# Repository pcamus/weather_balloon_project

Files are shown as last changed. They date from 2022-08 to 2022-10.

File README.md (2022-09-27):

# Weather balloon project

In this project I use a Raspberry Pi Pico and 2 extension modules to design a weather balloon experiment.

The purpose of this experiment is to measure flight parameters of the balloon (X,Y,Z acceleration, pressure and temperature).

The programming language is MicroPython.

## Hardware setup.

- A Raspbery Pi Pico.
- A [10-DOF IMU](https://www.waveshare.com/wiki/Pico-10DOF-IMU) from Waveshare.
- A battery module [Pico UPS A](https://www.waveshare.com/wiki/Pico-UPS-A) from Waveshare.

For the prototype I also use a [Quad GPIO Expander](https://www.waveshare.com/pico-quad-expander.htm) from Waveshare

*Prototype setup:*

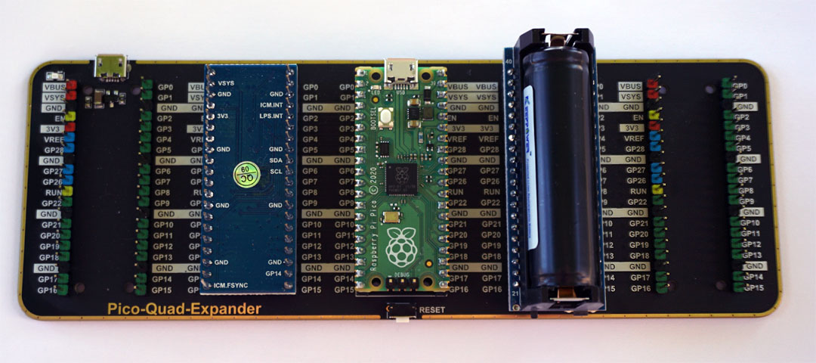
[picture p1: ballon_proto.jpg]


*The stacked version (wheight = 50 g) looks like that:*

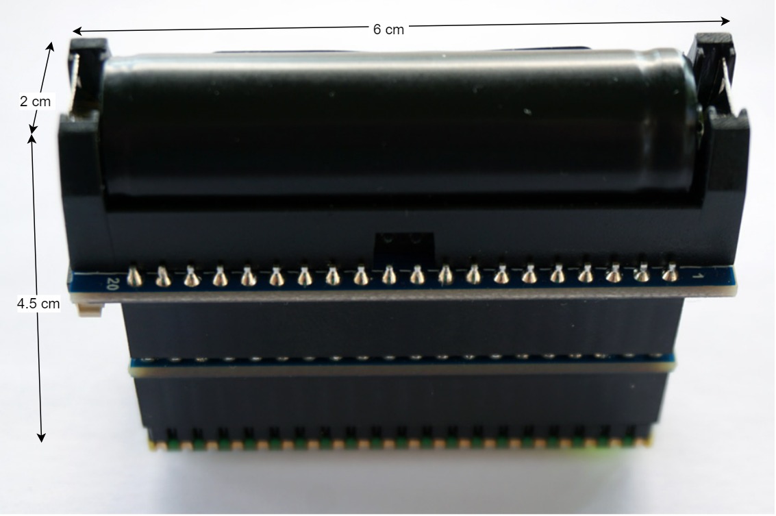
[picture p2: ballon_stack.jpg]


## Software (in MicroPython).

[acc_pt_log.py](acc_pt_log.py), performs data acquisition on the 10-DOF IMU. The code uses 2 modules icm20948_mod.py and
lps22 hb_mod.py (see embedded-sensors repository : [Pico_IMU_10DOF](https://github.com/pcamus/embedded-sensors/tree/main/Pico_IMU_10DOF/my_IMU_code))

The code appends X,Y,Z acceleration data from the ICM20948 chip to the binary file `acc.bin` and pressure + temperature from the LPS22HB chip to `Press_Temp.bin`.

Acceleration is sampled each 100 ms and pressure + temperature each second. Each value is converted into 2 bytes. 

[bin_to_csv.py](bin_to_csv.py), creates csv files from the binary files. 

## Enclosure.

A 3D enclosure with a removable lid was design with the Inventor software from Autodesk.

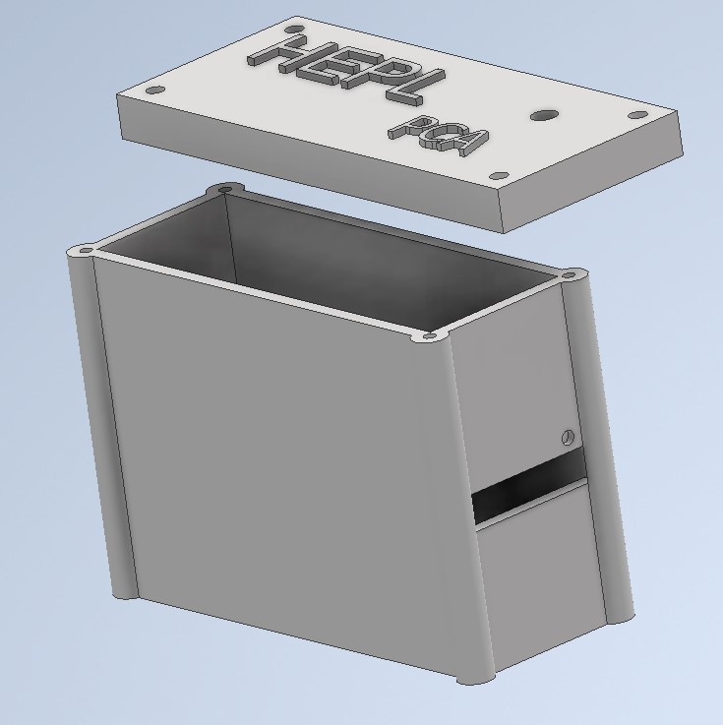
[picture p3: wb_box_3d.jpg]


Step and stl files are available in this repository.

Here is the view of the assembled system :

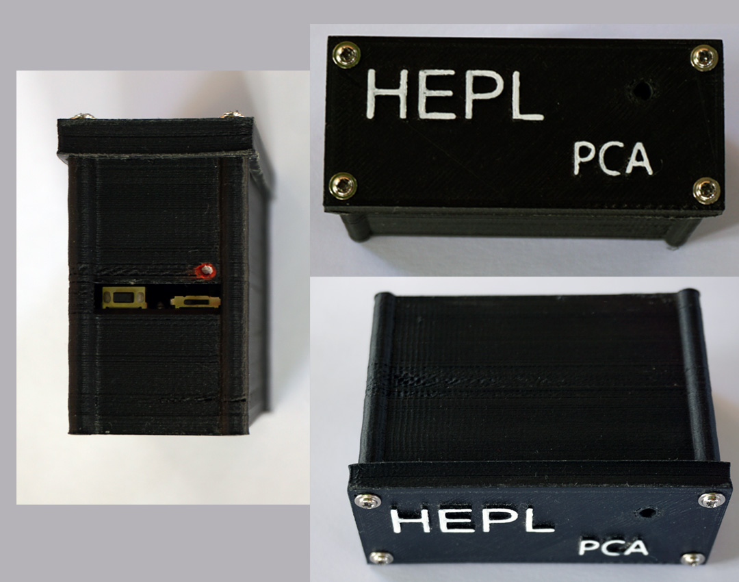
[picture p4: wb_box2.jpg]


The box was printed on an Anycubic i3 Mega with PLA filament.

The board assembly is simply slid into the box and wedged with a piece of foam on top.The start switch is located on the right of the side slot, the ON position is under the red and white dot.

Overall dimensions are 71 x 31 x 49 mm, weight is 84g.

## Using the system.

A manual with the procedure for using the system can be found [here](manual.md).

## Flight and results.

The module was launched by IRM on September 24, 2022.

See [here](flight_results) for the details.

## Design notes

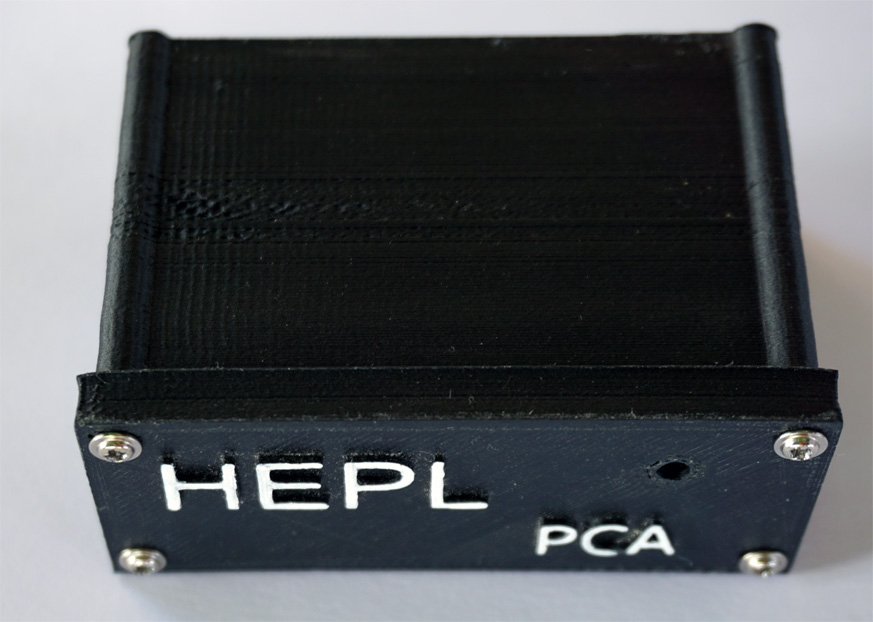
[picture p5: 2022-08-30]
wb_box1.jpg

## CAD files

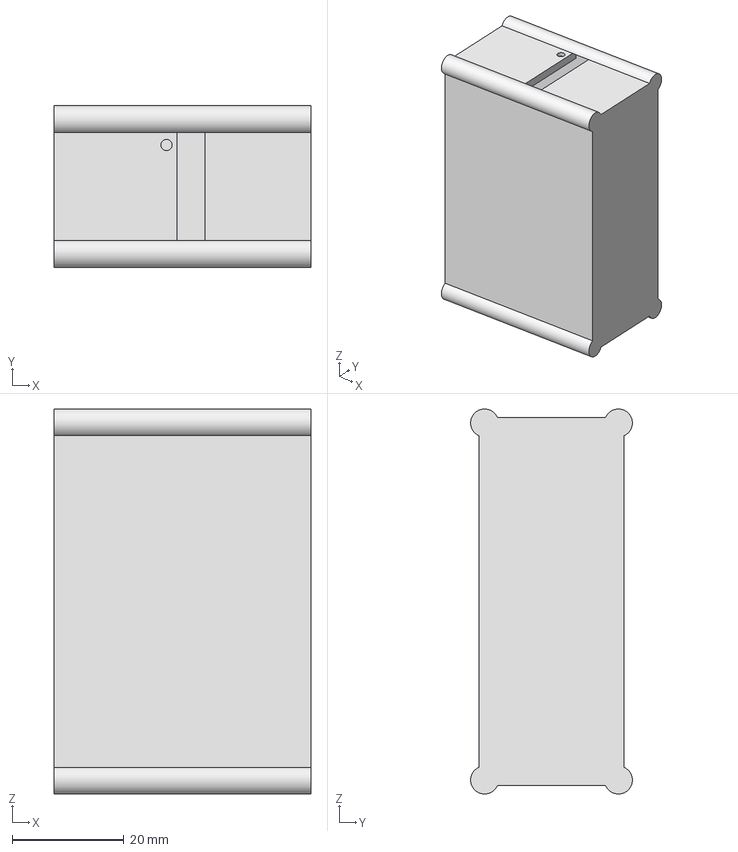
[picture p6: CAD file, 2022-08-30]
wb_box2.stp
46.0 x 29.0 x 69.0 mm

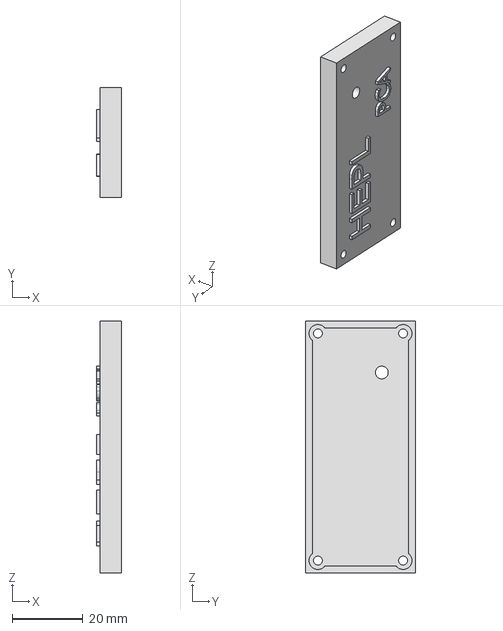
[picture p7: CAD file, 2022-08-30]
wb_box2_lid1.stp
7.00 x 31.0 x 71.0 mm

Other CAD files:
wb_box2.stl
wb_box2_lid1.stl

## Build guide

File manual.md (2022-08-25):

## How to use the system.

To program and retrieve files from the Raspberry Pi Pico I used the Thonny IDE.

I worked with two interpreters : 

- The default Thonny interpreter, running on my computer.
- The MicroPython interpreter running on the Pico board.

The interface is the following :

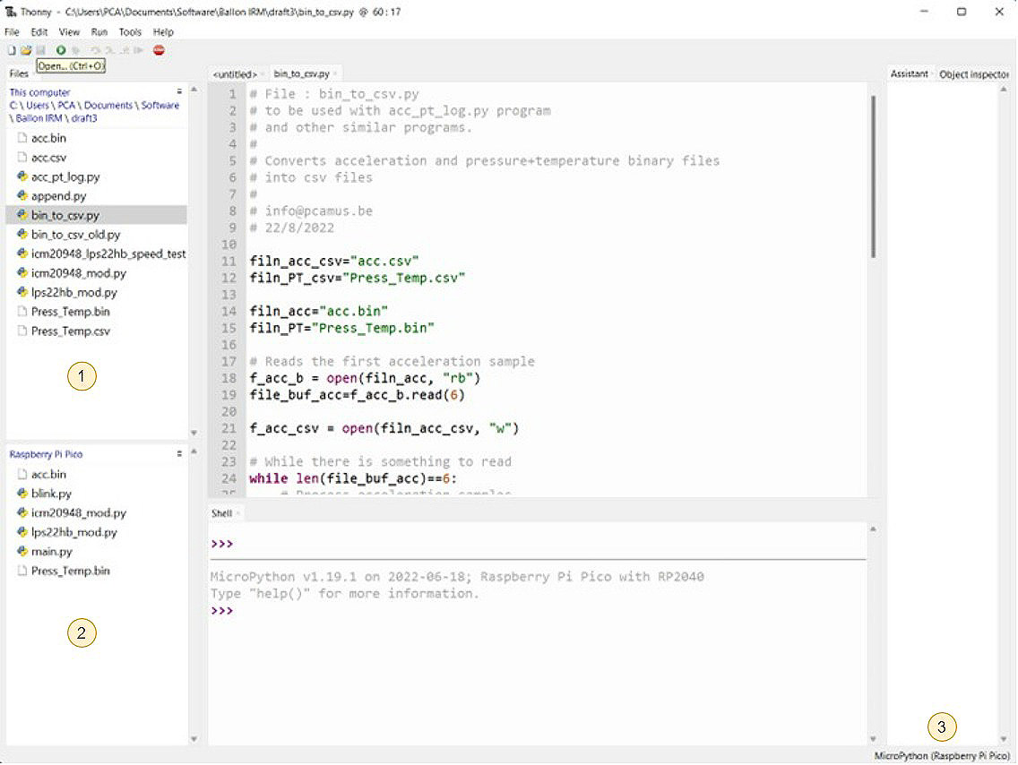
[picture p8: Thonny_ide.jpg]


- `1` is the current directory on my computer.
- `2` is the current directory on the Pico.
- `3` shows which interpreter is in use (to change click on this item).

To show the file windows click on View menu and then Files

*Interpreter choice :*

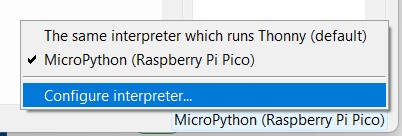
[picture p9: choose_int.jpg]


For information about installing MicroPython interpreter see [here](https://www.raspberrypi.com/documentation/microcontrollers/micropython.html).

### Program installation.

Connect the Pico to your computer with PICO-UPS-A board switch in OFF position.

In your working directory install `acc_pt_log.py`, `icm20948_mod.py`, `lps22hb_mod.py` and `bin_to_csv.py`

`icm20948_mod.py`, `lps22hb_mod.py` are in the embedded-sensors repository : [Pico_IMU_10DOF](https://github.com/pcamus/embedded-sensors/tree/main/Pico_IMU_10DOF/my_IMU_code)

Rename `acc_pt_log.py` as `main.py` (MicroPython starts automatically main.py at reset).

With the MicroPython interpreter selected, copy `main.py`, `icm20948_mod.py` and `lps22hb_mod.py` to the Pico (right click on the files then Upload to /)

Disconnect your computer. The logging will start when you switch ON the PICO-UPS-A and will last for a time equal to the value of the `LOG_TIME` variable (in `main.py`). The Pico LED will flash slowly twice indication that the initialisation of the chips is successful, then the LED will toggle at each sampling of the acceleration.

### Retrieving data files.

Connect the Pico to your computer with PICO-UPS-A board switch in OFF position and select the MicroPython interpreter.

This will automatically start a new acquisition, so stop it by clicking on the stop button. Then refresh the Raspberry Pi Pico file window (menu at the top right of the window).

Then click right successively on the `acc.bin` and `Press_Temp.bin` files and choose Download to... The files will be copied in your computer directory.

**Then switch to the default interpreter** (running on your computer) and run the `bin_to_csv.py` program. If you don't switch to the default interpreter the `bin_to_csv.py` program will try to create the csv files into the Pico flash memory which is not big enough for this !

After refreshing the file window, `acc.csv` and `Press_Temp.csv` will be there.

### Starting a new log session.

Connect the Pico to your computer with PICO-UPS-A board switch in OFF position and select the MicroPython interpreter.

This will automatically start a new acquisition, so stop it by clicking on the stop button. Then refresh the Raspberry Pi Pico file window (menu at the top right of the window).

Then click right successively on the `acc.bin` and `Press_Temp.bin` files and choose Delete. The files will be removed from the Pico flash memor thus leaving room for a new data logging.

Disconnect your computer. The logging will start when you switch ON the PICO-UPS-A.

### Using the data.

After conversion, two files are available : 

- `acc.csv` with the X,Y,Z acceleration values. In this setup the accelerations range from -32768 à +32767 corresponding to -2g to +2g and the sampling rate is 100 ms.
- `Press_Temp.csv` with pressure and temperature values. The pressure is in hPa and the temperature in Celsius degree with one decimal. The sampling rate is 10s.

A row with all 0 indicates the beginning of a new logging session.

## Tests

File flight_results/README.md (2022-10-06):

# Flight results

Due to an incorrect value for the flight duration in the MicroPython program, the data logging was only made for 30 minutes of which only 10 correspond to the flight (up to an altitude of 2600 m).

The flight peaked at 34 km altitude. Its total duration was 2h15.

**Pressure variation during the flight:**

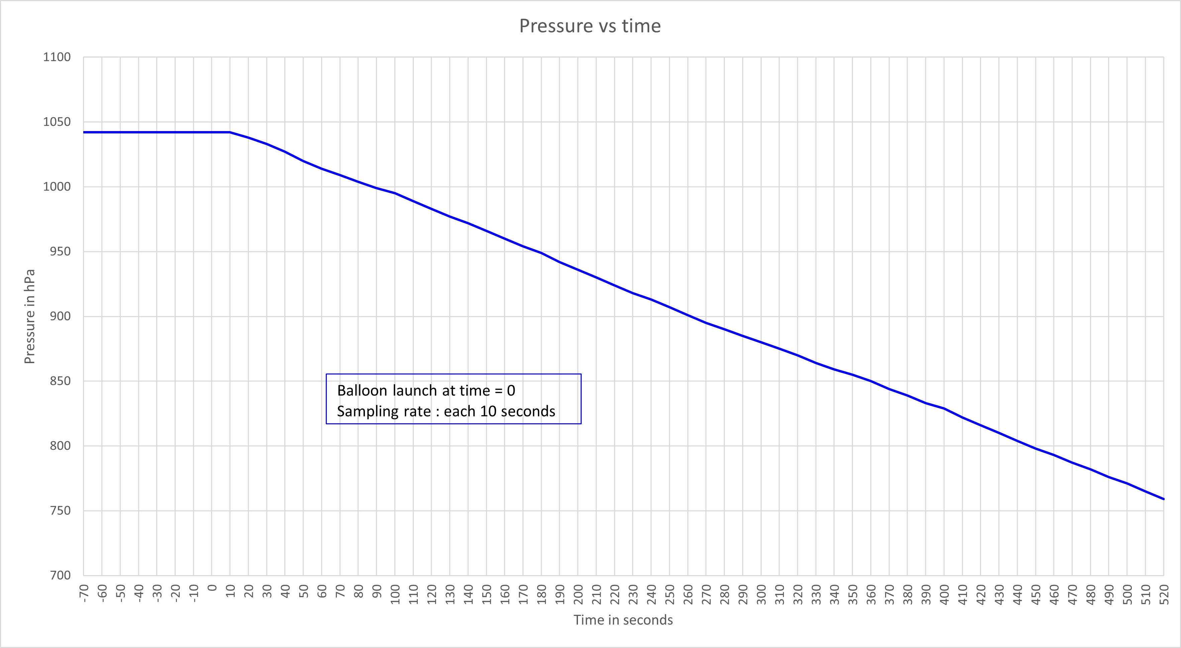
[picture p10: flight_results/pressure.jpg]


The formula giving altitude (h) versus pressure (p) is:  the following $h=\frac{R.T}{\mu.g}ln(\frac{p}{p_0})$

With : 

- h : altitude above ground
- R : ideal gaz constant = 8.3143 J/K.mol
- T : temperature at altitude h (in °K)
- $\mu$ : air molar mass = 0.02896 kg/mol
- g : gravity of earth = 9.81 m/$s^2$
- $p_0$ : pressure at ground

Substituing with the numerical values leads to $h=-29.2656\ T\ ln(\frac{p}{p_0})$

For example at t = 520 s, the measured pressure was 759 hPa , with a ground pressure $p_0$ of 1042 hPa and a temperature of 290.5°K, the altitude above ground h given by the formula is: **2694 m**.

*The altitude above ground given by the tracking at this moment was: **2960 m**.*

**Altitude calculated from the pressure vs altitude with constant rate of ascent:**

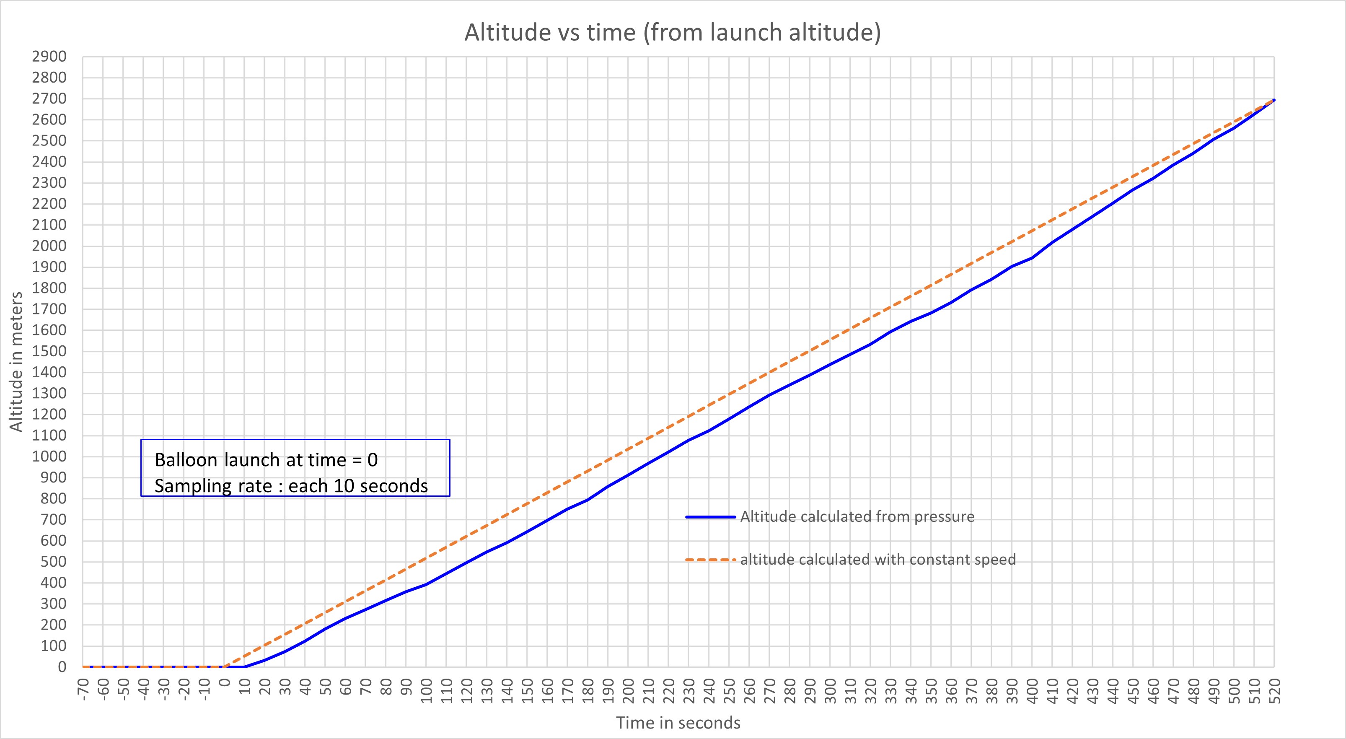
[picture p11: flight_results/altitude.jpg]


The average speed is **5.18 m/s**. 

Balloon speed calculation from Newton's law with its differential equation resolution is [here](balloon_equation.pdf). Integration is made with sympy : [edif_bal.py](edif_bal.py)

The difference between measured speed and calculated speed is due to our approximate knowledge of some balloon parameters.

\
**Vertical acceleration:**

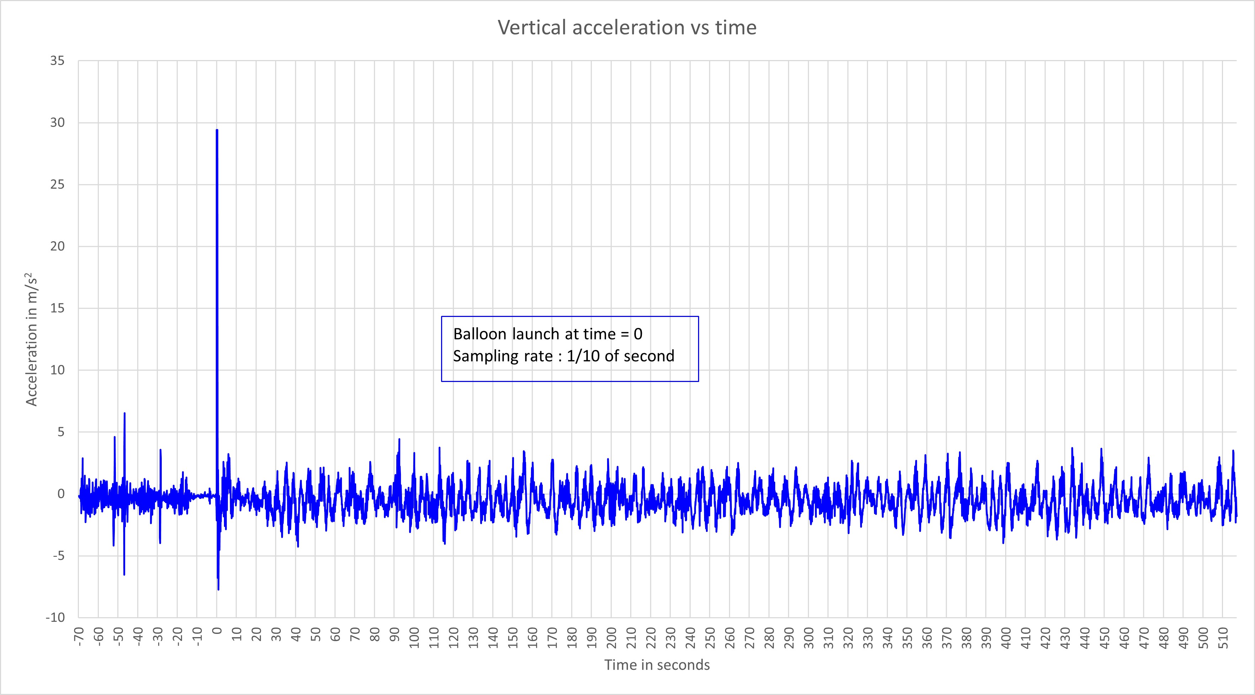
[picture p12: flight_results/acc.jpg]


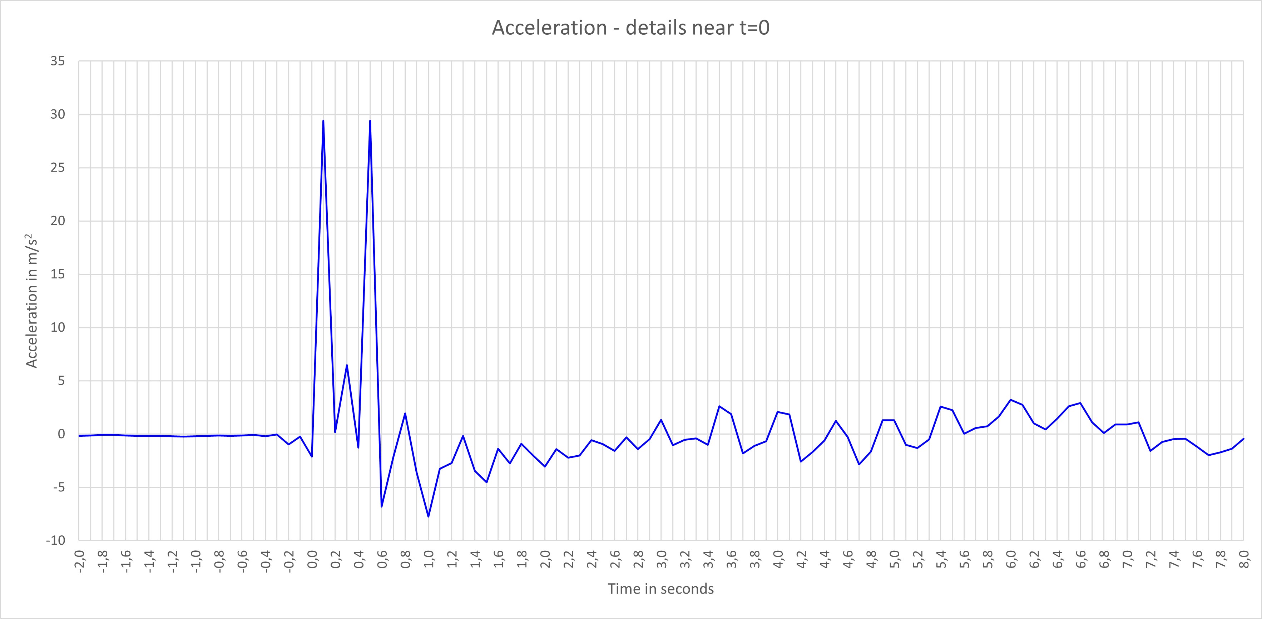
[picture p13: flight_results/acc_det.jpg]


The acceleration curve is not usable to compute the speed and altitude for several reasons:

- The time resolution (1/10e s) is too large to have a correct picture of the motion.
- There are too many vertical oscillations (mass-spring effect due to the balloon).
- The wind disturbs the motion...

\
Thank you to the IRM for allowing us to use its balloon and a very big thanks for the radio amateurs of the [UBA](https://www.uba.be/fr/radioamateurisme) who recovered the probe.

The flight dashboard is [here](https://grafana.v2.sondehub.org/d/HJgOZLq7k/basic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).

[Here is a pic of me ready to launch the balloon](IRM2209_03.jpg).

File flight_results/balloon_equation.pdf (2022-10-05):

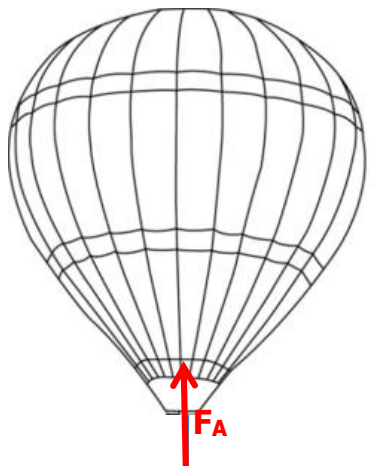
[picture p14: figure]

Weather balloon equation | philippe.camus@hepl.be | 1/4.

Weather balloon speed.

Equation.

List of forces:

FA Archimedes thrust.
P : balloon and payload weight. Ff : friction force in the air.

FA = ρair Vballoon g

P = mtotal g

Ff = ½ Cx ρair S v² = drag force.

Cx is the air penetration (or drag) coefficient
S the effective area of the object (largest section perpendicular to the movement). v is the vertical speed of the balloon

Newton’s equation: sum of the forces (with respective sign) = m a.

FA − P − FA = m total a = m total

dv(t)
dt

ρair Vballoon g − mtotal g −

1
2

CxρairS v

2
(t) = m total

dv(t)
dt

That could be written :

dv(t)
dt + Av

2
(t) − B = 0

With :

A =

1

2mtotal

CxρairS B = g (

ρair Vballoon

mtotal

− 1)

P

Ff

Limit values.

Maximum boardable weight at take-off (acceleration must be positive):

ρair Vballoon g

mtotal

− g = B =

dv(t)
dt ≥ 0 → mtotal ≤ ρair Vballoon

B>0 is needed to allow the take-off of the balloon.

Limit speed: speed for which the acceleration is zero.

ρair Vballon g − mtotal g −

1
2

CxρairS v

2
(t) = 0

→ vlim = √
2g
CxρairS

(ρair Vballoon − mtotal) = √
B
A

If we take the numerical value for a typical balloon (1.5 m in diameter)

ρair = 1.22 kg/m³, Vballoon=1.77m³, mtotal = 1.4 kg, S= 1.77 m², Cx=0.45 g=9.81 m/s²

we obtain: A = 0.347 m⁻¹ et B=5.321 m/s²

vlim = √13.6/0.53 = 3.9 m/s

Maximum mass to allow take-off: mtotal = 2.16 kg

Analytical solution.

The speed equation is:

dv(t)
dt + Av(t)

2 − B = 0 witℎ A > 0 and B > 0

It is a first order nonlinear differential equation. We can solve it by separation of variables :

dv
B − Av

2 = dt

Integrating both sides gives :
∫

dv
B − Av

2 = ∫ dt

Using Sympy to integrate and doing some clean-up gives:

ln (v(t) + √
B
A

) − ln (v(t) − √
B
A

)

m

= t + k witℎ m = 2√AB

Taking exponential of both sides leads to:

e

ln(v(t)+√
B
A

)−ln(v(t)−√
B
A

)
= e

m(t+k)
v(t) + √
B
A
v(t) − √
B
A

= Ke

mt

If speed=0 at t=0 then K=-1

v(t) + √
B
A

= − (v(t) − √
B
A

)e

mt

That is :
v(t) = √
B
A

(
e

mt − 1
emt + 1

)

With the previous numerical values, the equation is: v(t) = 3.9 (

e

2.7176t−1
e

2.7176t+1

)

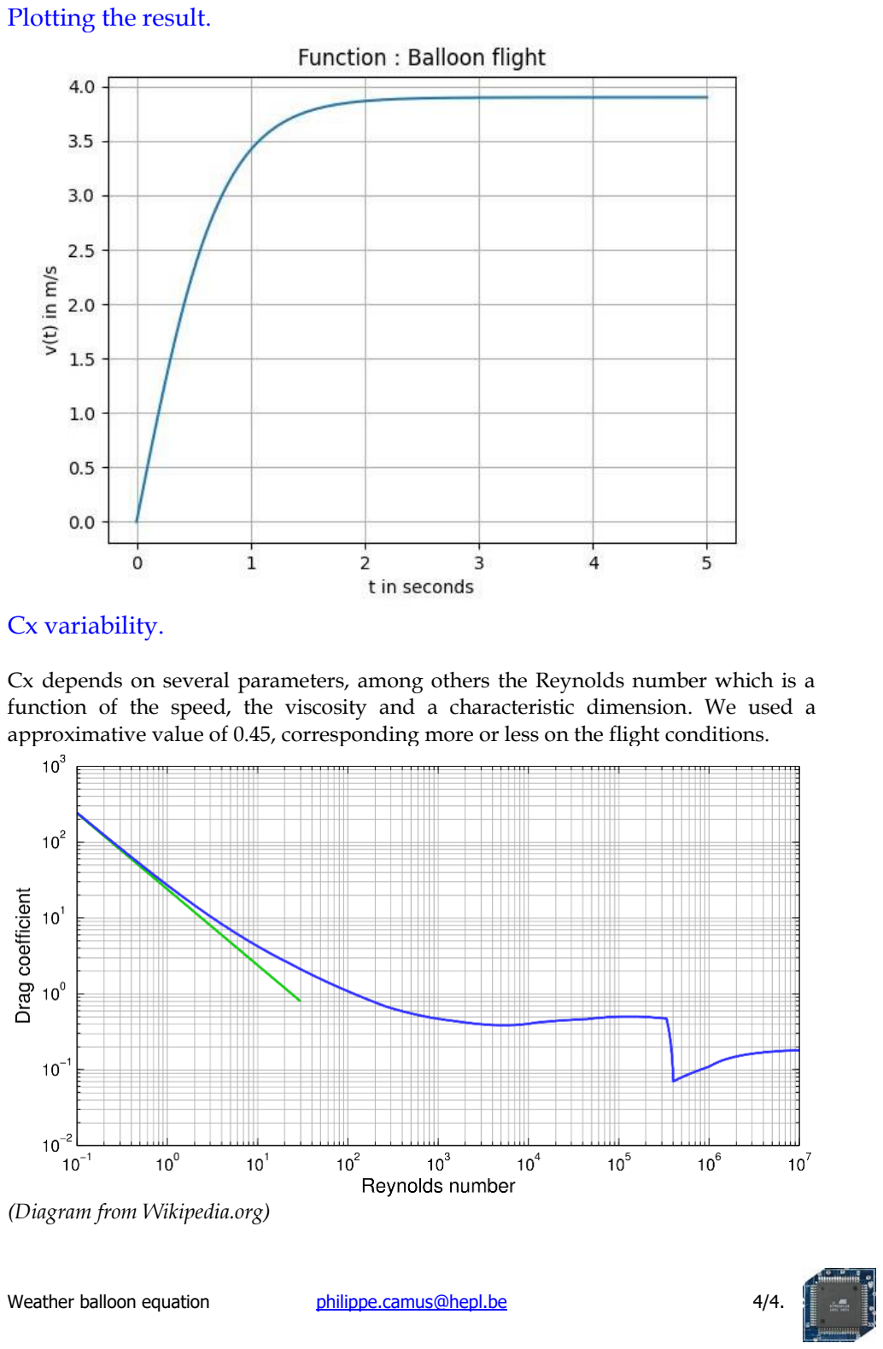
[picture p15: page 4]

Plotting the result.

Cx variability.

Cx depends on several parameters, among others the Reynolds number which is a function of the speed, the viscosity and a characteristic dimension. We used a approximative value of 0.45, corresponding more or less on the flight conditions.

(Diagram from Wikipedia.org)

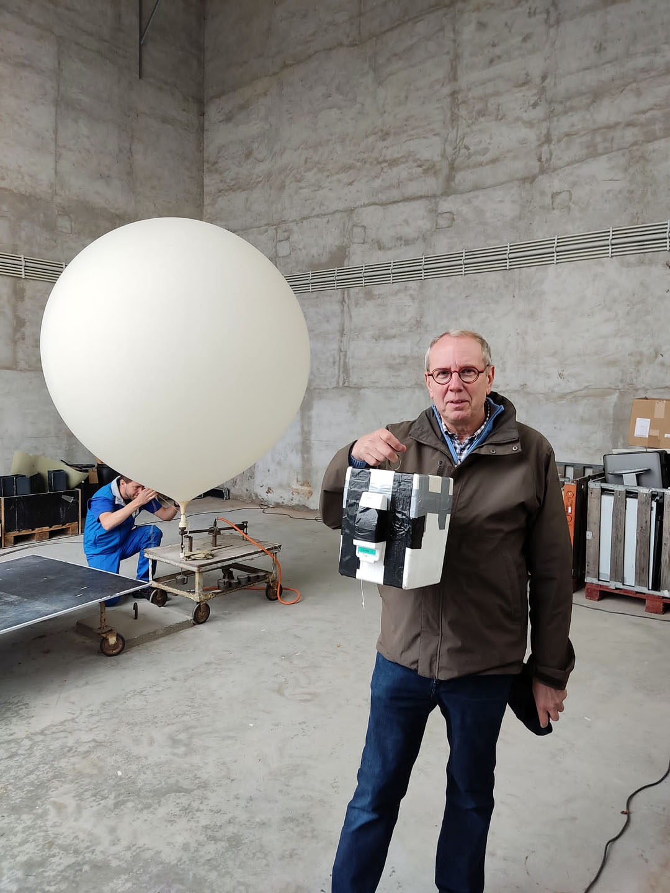
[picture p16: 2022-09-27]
flight_results/IRM2209_03.jpg

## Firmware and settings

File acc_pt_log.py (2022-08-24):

# File : acc_pt_log.py
#
# Log acceleration, pressure and temperarure 
# Takes 10 X,Y,Z acceleration samples per second during 10 sec (6 bytes for a X,Y,Z sample) 
# Then one pressure and one temperature sample (4 bytes).
# Repeat the process during a specified time
#
# Append the result to binary files : 10 s = 600 bytes for acceleration
# and 4 bytes for pressure and temperature.
#
# Chip ICM20948 : https://www.waveshare.com/w/upload/5/57/ICM-20948-v1.3.pdf
# Chip LPS22HB : https://www.waveshare.com/w/upload/2/20/Lps22hb.pdf
# Pico 10-DOF IMU module : https://www.waveshare.com/wiki/Pico-10DOF-IMU
#
# info@pcamus.be
# 22/8/2022

from icm20948_mod import *
from lps22hb_mod import *
from machine import Pin
import utime
import uos

LOG_TIME = 1800 # Logging time in seconds

# Calibration values to add to temperature and pressure (for my LPS22HB sensor).
temp_cal = -2.3
pres_cal = 40

# Creates sensors instances
icm20948=ICM20948()
lps22hb=LPS22HB()

# Heart beat and status LED
hb = Pin(25, machine.Pin.OUT)

file_buf_acc= bytearray(600) # 100 x 2 bytes x 3 axis
file_buf_PT= bytearray(4) # pressure = 2 bytes, temperature 2 bytes

filn_acc="acc.bin"
filn_PT="Press_Temp.bin"

# In this version I don't remove the file automatically at reset.
# The files must be removed manually when we start an new log.
# Otherwise the new log is appended to the previous one.

# 6 x 0x00 is written in the acc.bin indicating the begining of a new record.
f = open(filn_acc, "ab")
f.write(bytearray(6)) # bytearray with 6 elements initialized to 0
f.close()

# and 4 x 0x00 is written in the Press_Temp.bin.
f = open(filn_PT, "ab")
f.write(bytearray(4)) # bytearray with 4 elements initialized to 0
f.close()

# # Removes old copy of files if they exist
# try:
#     uos.remove(filn_acc) 
# except:
#     pass
# 
# try:
#     uos.remove(filn_PT) 
# except:
#     pass

# Two blinks means initialization success
hb.on() 
utime.sleep_ms(100)
hb.off()
utime.sleep_ms(100)
hb.on() 
utime.sleep_ms(100)
hb.off()

log_start=utime.time() # Start time of logging
pressure, temperature = lps22hb.LPS22HB_READ_P_T() # reads once before to remove false values

while(True):
       
    for i in range(100): # Takes 100 acceleration samples
        
        start=utime.ticks_ms()
       
        Accel=icm20948.icm20948_Accel_Read().copy()
        
        # Stores in a bytearray buffer after converting in the bytearray element format
        buf_index=i*6
        file_buf_acc[buf_index]=Accel[0] // 256   # Acc X MSB
        file_buf_acc[buf_index+1]=Accel[0] % 256  # Acc X LSB
        file_buf_acc[buf_index+2]=Accel[1] // 256 # Acc Y MSB 
        file_buf_acc[buf_index+3]=Accel[1] % 256  # Acc Y LSB
        file_buf_acc[buf_index+4]=Accel[2] // 256 # Acc Z MSB
        file_buf_acc[buf_index+5]=Accel[2] % 256  # Acc Z LSB
        
        while utime.ticks_diff(utime.ticks_ms(), start)<100:  # Takes a sample each 100 ms
            pass     
        
        hb.toggle() # toggle a led to have a heart beat

    pressure, temperature = lps22hb.LPS22HB_READ_P_T() # and takes one pressure and temperature
                                                       # measurement each 10 sec
 
    # Writes acceleration samples to a binary file
    f = open(filn_acc, "ab")
    f.write(file_buf_acc)
    f.close()
    
    # Convert pressure and temperature data to bytearray
    int_pressure=int(pressure + pres_cal)
    int_temperature=int((temperature + temp_cal)*10) # scales temperature to keep tenth of degree
                 
    file_buf_PT[0]=int_pressure // 256
    file_buf_PT[1]=int_pressure % 256
    file_buf_PT[2]=int_temperature // 256                 
    file_buf_PT[3]=int_temperature % 256
    
    # Writes to a binary file
    f = open(filn_PT, "ab")
    f.write(file_buf_PT)
    f.close()
       
    # Check for end of logging.
    if (utime.time()-log_start) > LOG_TIME :
        hb.off()
        sys.exit()
    

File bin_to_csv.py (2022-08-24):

# File : bin_to_csv.py
# to be used with acc_pt_log.py program
# and other similar programs.
#
# Converts acceleration and pressure+temperature binary files
# into csv files
#
# info@pcamus.be
# 22/8/2022

filn_acc_csv="acc.csv"
filn_PT_csv="Press_Temp.csv"

filn_acc="acc.bin"
filn_PT="Press_Temp.bin"

# Reads the first acceleration sample
f_acc_b = open(filn_acc, "rb")
file_buf_acc=f_acc_b.read(6)

f_acc_csv = open(filn_acc_csv, "w")

# While there is something to read
while len(file_buf_acc)==6:
    # Process acceleration samples
    acc_x=file_buf_acc[0]*256+file_buf_acc[1]
    if acc_x>=32767:             
        acc_x=acc_x-65535

    acc_y=file_buf_acc[2]*256+file_buf_acc[3]
    if acc_y>=32767:             
        acc_y=acc_y-65535
        
    acc_z=file_buf_acc[4]*256+file_buf_acc[5]
    if acc_z>=32767:             
        acc_z=acc_z-65535
    
    f_acc_csv.write("%d;%d;%d\n"%(acc_x,acc_y,acc_z))    

    file_buf_acc=f_acc_b.read(6)    

f_acc_b.close()
f_acc_csv.close()

# Reads the first pressure and temperature log
f_PT_b = open(filn_PT, "rb")
file_buf_PT=f_PT_b.read(4)

f_PT_csv = open(filn_PT_csv, "w")

# While there is something to read
while len(file_buf_PT)==4:
    # Process pressure and temperature samples
    pressure = file_buf_PT[0]*256+file_buf_PT[1]
    temperature = (file_buf_PT[2]*256+file_buf_PT[3])/10
    f_PT_csv.write("%d;%4.1f\n"%(pressure, temperature))
    file_buf_PT=f_PT_b.read(4)

f_PT_b.close()
f_PT_csv.close()
